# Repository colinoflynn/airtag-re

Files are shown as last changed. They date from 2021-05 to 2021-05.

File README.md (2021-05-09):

**NOTE 1: please fork this repo if using for your own use. I don't intend for this to be a central resource for airtag RE, more just some useful references for you to build on.**

**NOTE 2: This repo will not have any firmware or similar. Issues are disabled because the repo does not have any issues, it's perfect.**

## Test Points

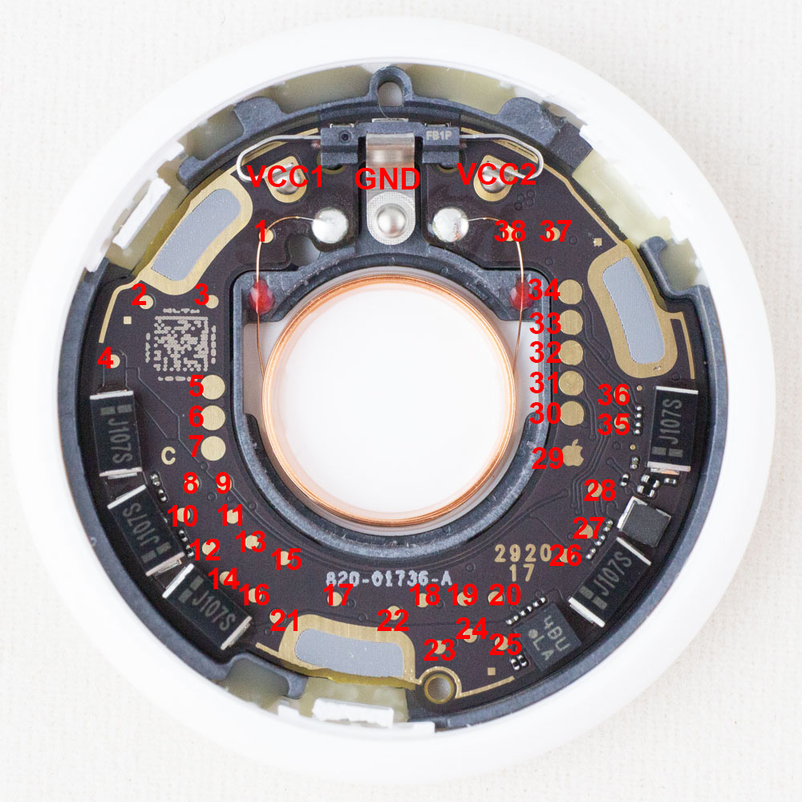
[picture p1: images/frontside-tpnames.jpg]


|Name | Description |
|-----|---|
|VCC1 | +3.0V input (1 of 2 - both needed)* |
|VCC2 | +3.0V input (2 of 2 - both needed)* |
|GND  | Ground | 
| | |
| 5 | VCC2 (Connects to VCC2 input) |
| 6 | VCC1 (Connects to VCC1 input) |
| 7 | GND |
| 8 | nRF ball E2 (P0.16) |
| 9 | nRF ball D3 (P0.26) |
| 19  | 1.8V SPI Flash - Data In (COPI) / nRF ball H3 (P0.16) |
| 20  | 1.8V SPI Flash - Data Out (CIPO) /nRF ball H4 (P0.15) |
| 21  | 1.8V SPI Flash VCC |
| 22  | 1.8V SPI Flash - SCLK / nRF ball G3 (P0.17) |
| 24  | 1.8V SPI Flash - Chip Select (CS)/ nRF ball F4 (P0.11) |
| 29  | Apple Logo :) GND |
| 30  | nRF ball H1 (P0.21/nRST) |
| 31  | nRF ball H2 (P0.18/SWO) |
| 34  | 1.8V from nRF |
| 35  | nRF ball F1 (SWCLK) |
| 36  | nRF ball G1 (SWDIO) |

*NOTE: The big pads under the VCC1/VCC2 battery terminals are NOT connected.
So if you remove the battery terminals you need to solder to the smaller pads where
the terminals connected! I just apply 3.3V here, it's assumed the device will be designed to work with some variation.

### SPI Connections

The SPI connections (SCK/DI/DO/CS) are as above. If talking to the SPI flash chip note the following:

* You need to apply 1.8V on test point 21 to force the flash on.
* The nRF occasionally talks to SPI flash (especially when stuff like adding a device happens) which will interrupt this. But most of time the flash is powered off and thus the pins are tri-stated.

The nrf controls power to the SPI flash, so you need to override it by supplying 1.8V on test point 21.

## Images

See repo for higher resolution.

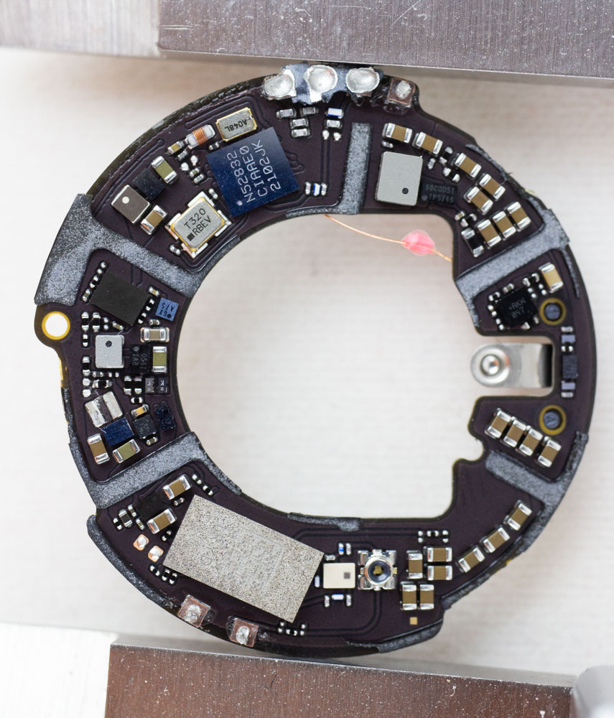
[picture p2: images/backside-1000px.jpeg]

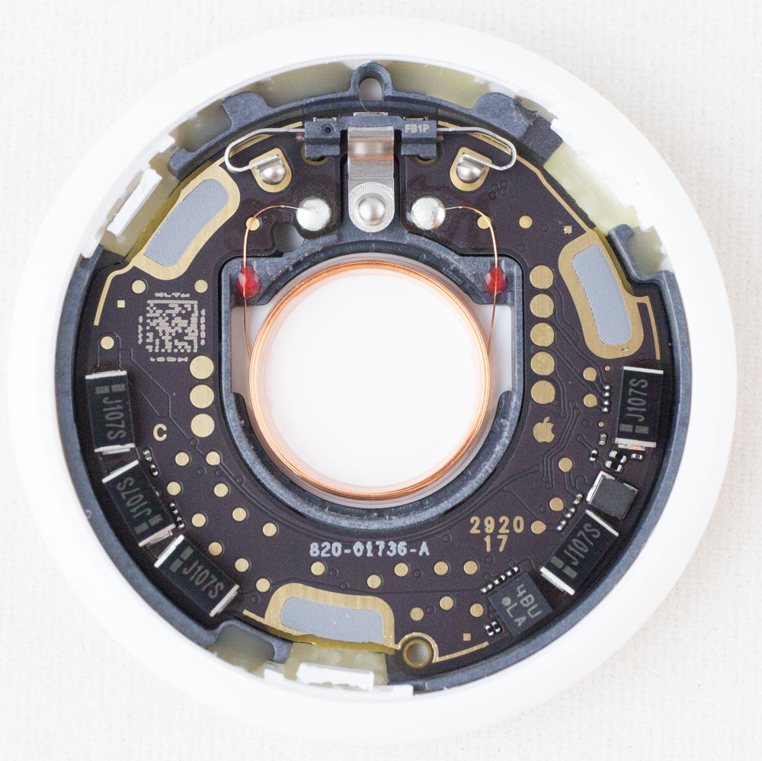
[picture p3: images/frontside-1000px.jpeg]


## License

This repo is licensed CC-BY-4.0 (to say explicitly - photos can be used commercially and only require attribution to *Colin O'Flynn*, no additional permission request is needed).

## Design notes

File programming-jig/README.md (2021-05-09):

# Programming Jig / Test Point Adapter

You will need to customize the adapter for your pogo pins and test points you want. The easiest way to do this is via Fusion360 which should have an overlay of the image in the .f3d file:

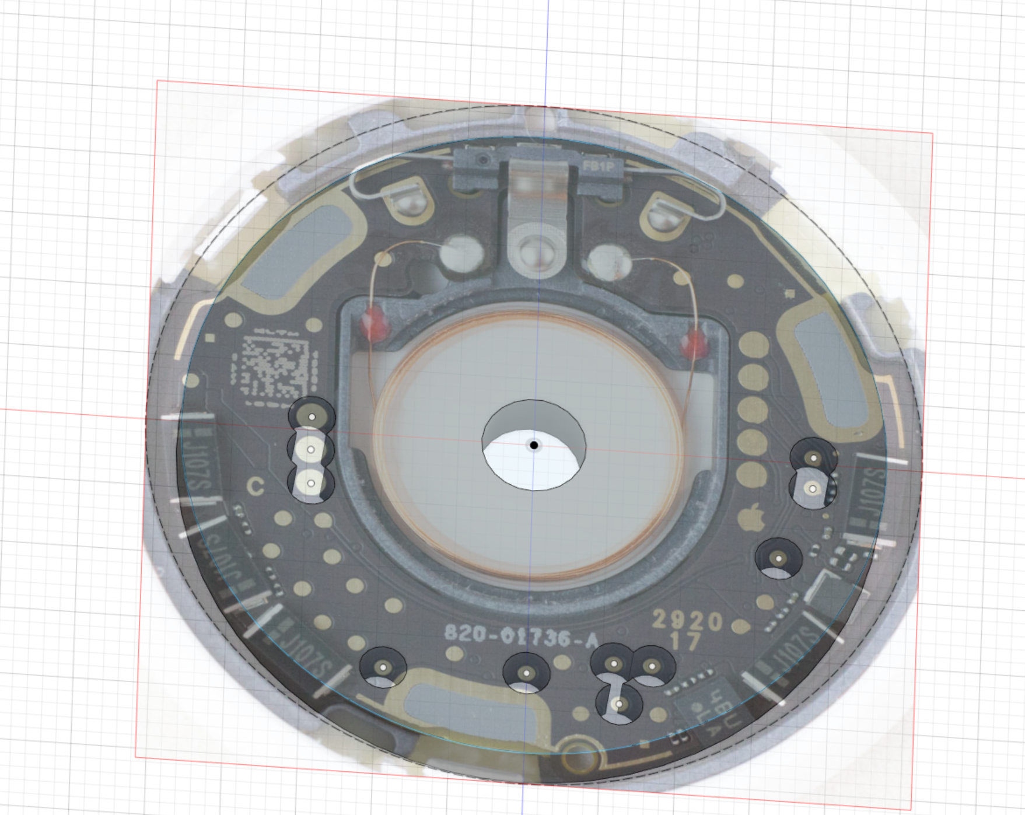
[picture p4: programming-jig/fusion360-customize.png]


If it requires the image, point it to `frontside-26mm-cropped.jpg` in the `images` directory.

The example here was printed for 1mm pins, but due to the 3D printer you'll need to adjust the hole size. The fusion360 history should allow you to easily adjust them all in one shot.

## Assembly

The jig is assembled using a 4-40 bolt as a spacer:

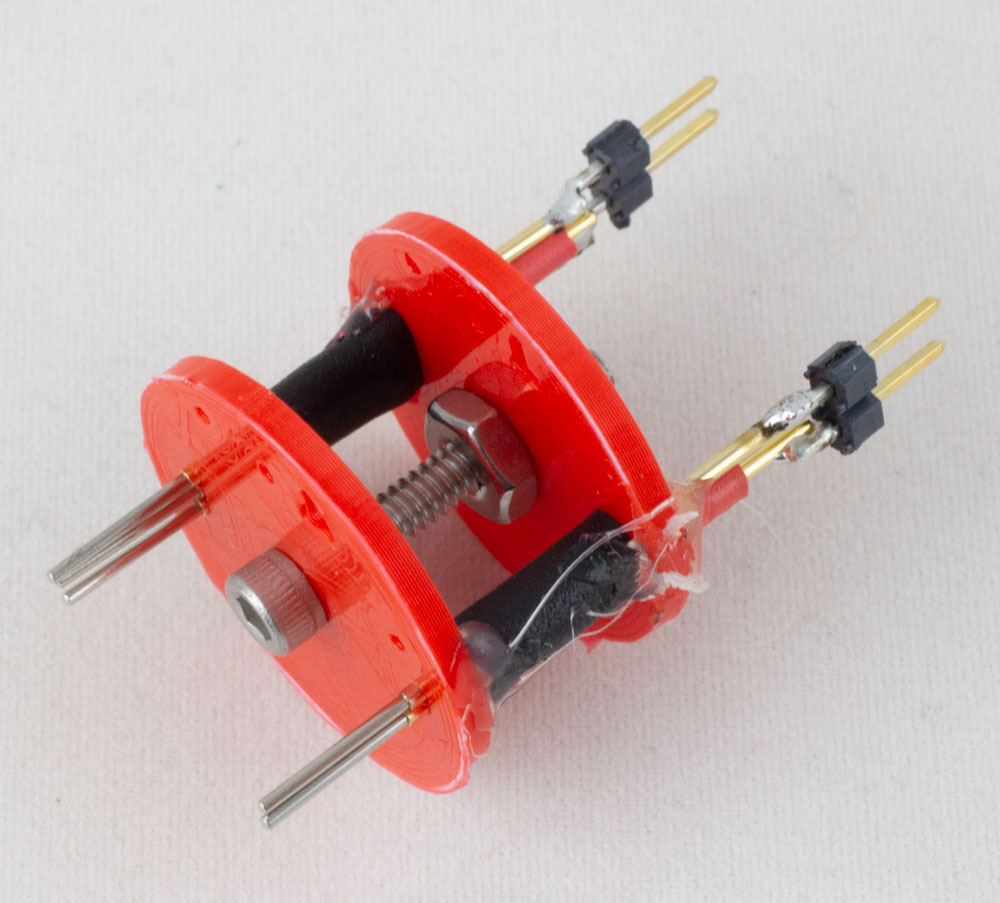
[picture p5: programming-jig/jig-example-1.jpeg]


You'll need to add insulators for the pogo pins due to how closely they will fit. If you get smaller pins (these are 1mm diameter) you might be able to get away with just the 3D printed holes.

## Usage

Currently I was testing with hold it on - you'll want to 3D print a better system than that:

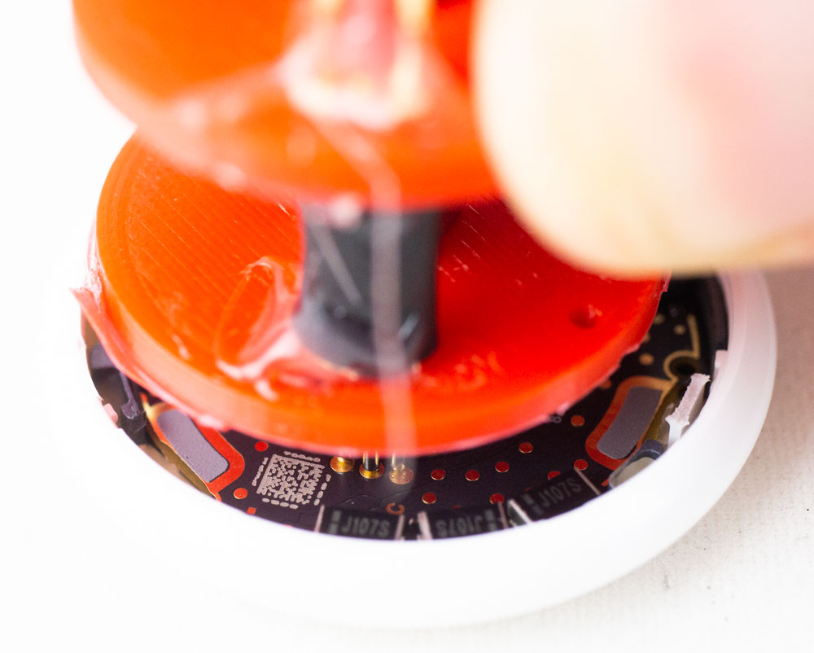
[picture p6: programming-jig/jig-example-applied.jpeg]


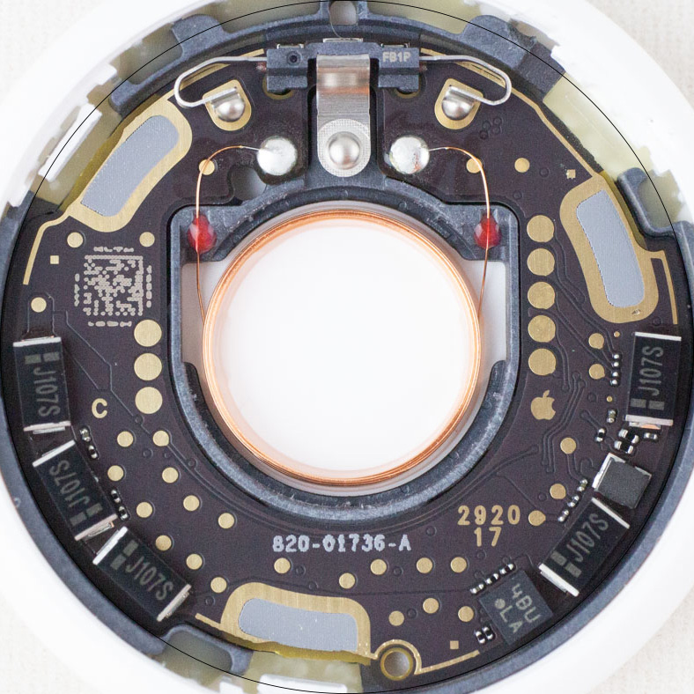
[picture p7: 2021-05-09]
images/frontside-26mm-cropped.jpg

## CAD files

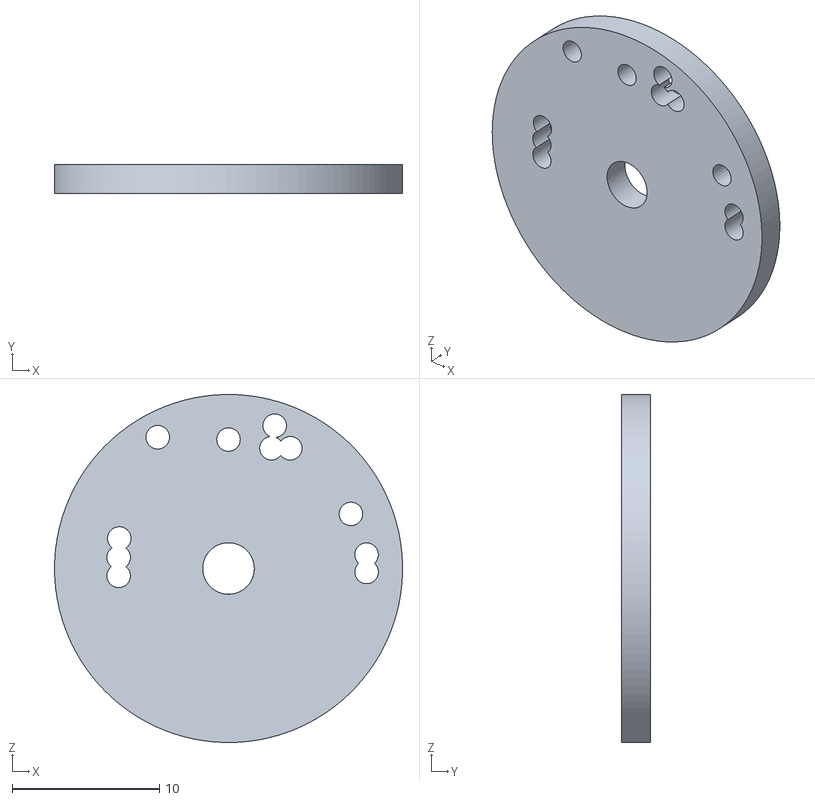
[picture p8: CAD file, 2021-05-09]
programming-jig/airtag-beta-base.stl
23.6 x 2.00 x 23.6

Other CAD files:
programming-jig/airtag-beta-base.f3d

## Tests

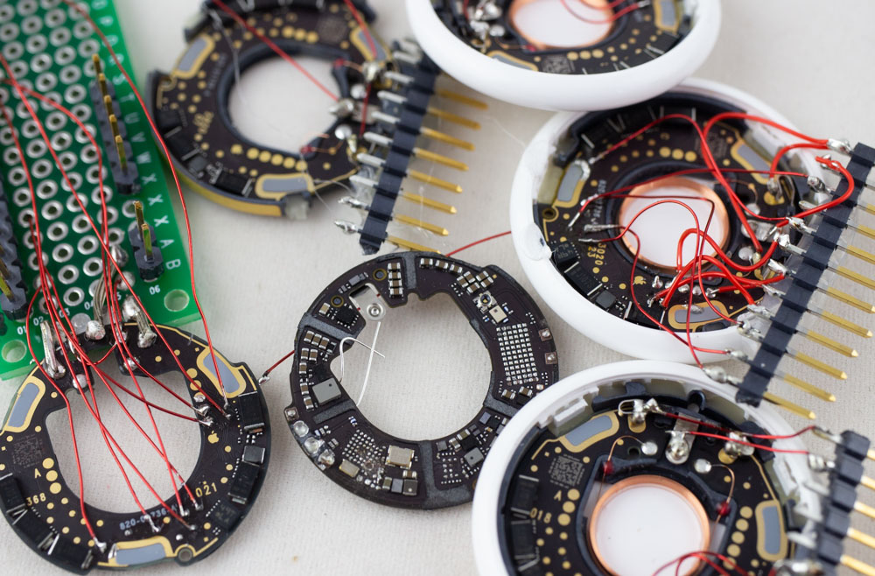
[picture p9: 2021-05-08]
images/airtag-tests.jpeg

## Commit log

2021-05-07 Add docs on power for SPI
2021-05-08 Add note about spi flash
2021-05-08 Add note about 3.3V probably OK.
2021-05-09 Add jig
    [airtag-beta-base.f3d, airtag-beta-base.stl]
